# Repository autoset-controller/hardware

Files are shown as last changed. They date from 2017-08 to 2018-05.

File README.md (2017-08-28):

# Autoset Controller
> Theatrical Controller for Thesis Project

Program for wireless control of motorized platforms in a stage space.

## Developing

### Built With
List main libraries, frameworks used including versions (React, Angular etc...)

### Prerequisites
What is needed to set up the dev environment. For instance, global dependencies or any other tools. include download links.

## Versioning

We can maybe use [SemVer](http://semver.org/) for versioning. For the versions available, see the [link to tags on this repository](/tags).

## Configuration

Here you should write what are all of the configurations a user can enter when
using the project.

## Style guide

Our git style will be implemented from [Wearhive's project guidelines](https://github.com/wearehive/project-guidelines#git).

## Api Reference

If the api is external, link to api documentation. If not describe your api including authentication methods as well as explaining all the endpoints with their required parameters.

## Licensing

State what the license is and how to find the text version of the license.

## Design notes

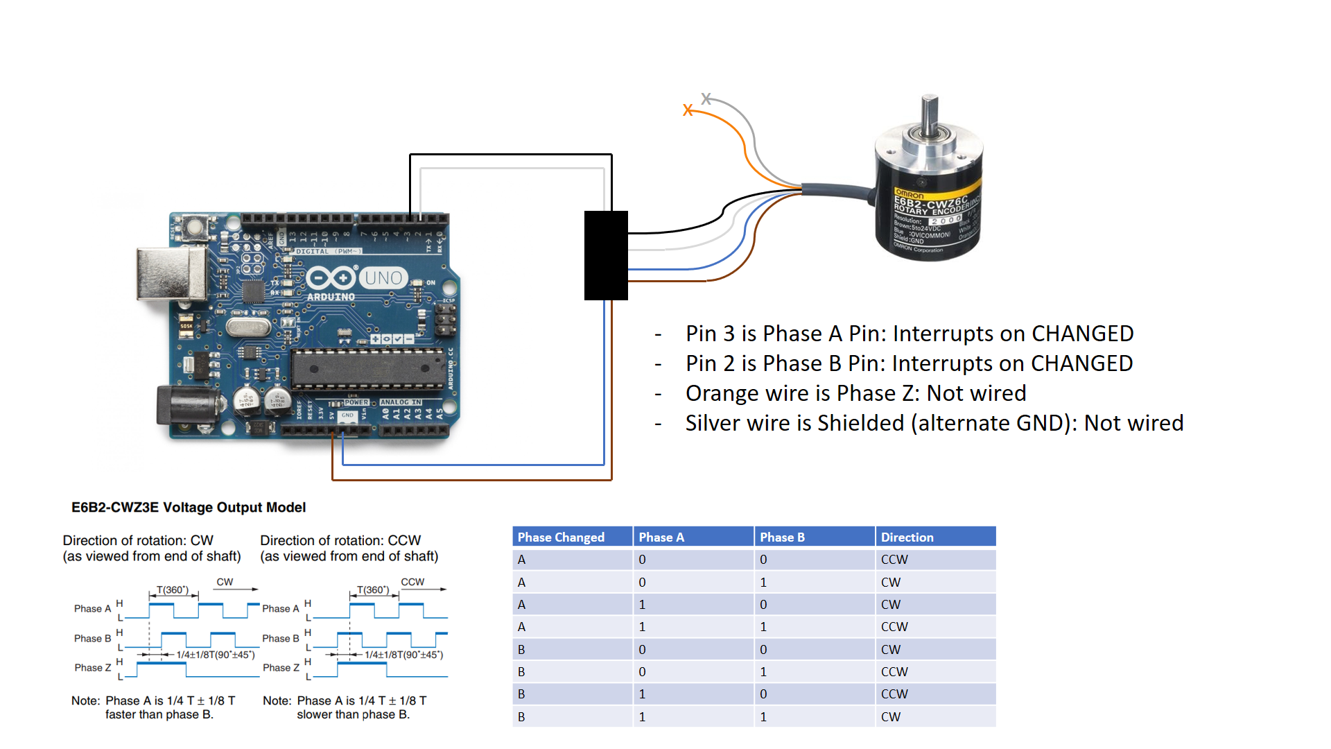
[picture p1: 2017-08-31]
Hardware Interface/Circuit Diagrams/Rotary Encoder E6C2-CW3ZE.png

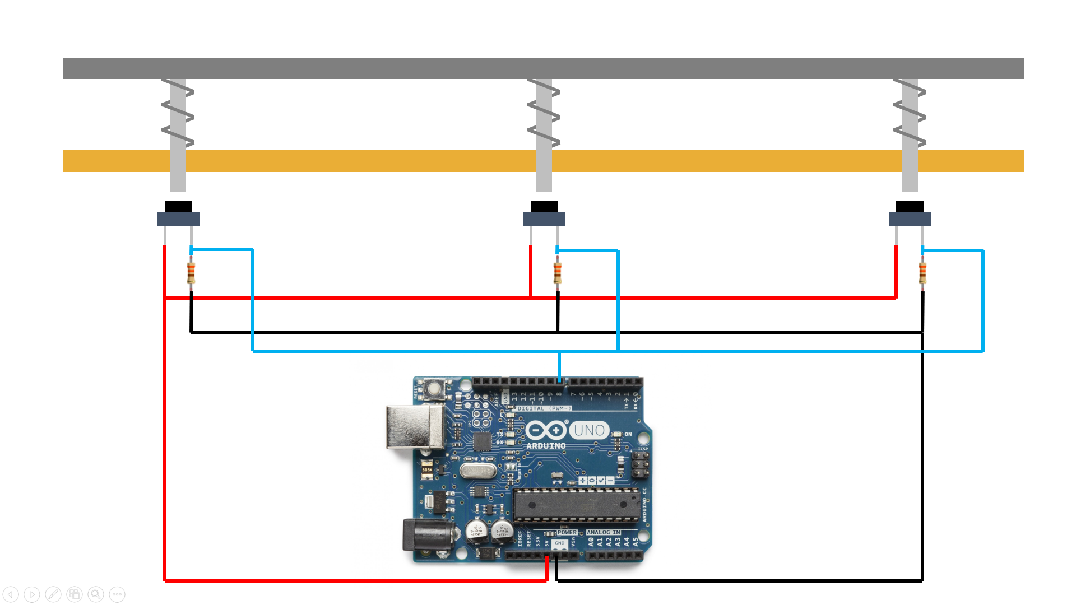
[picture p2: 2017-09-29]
Hardware Interface/Circuit Diagrams/Bumper HOUSE.png

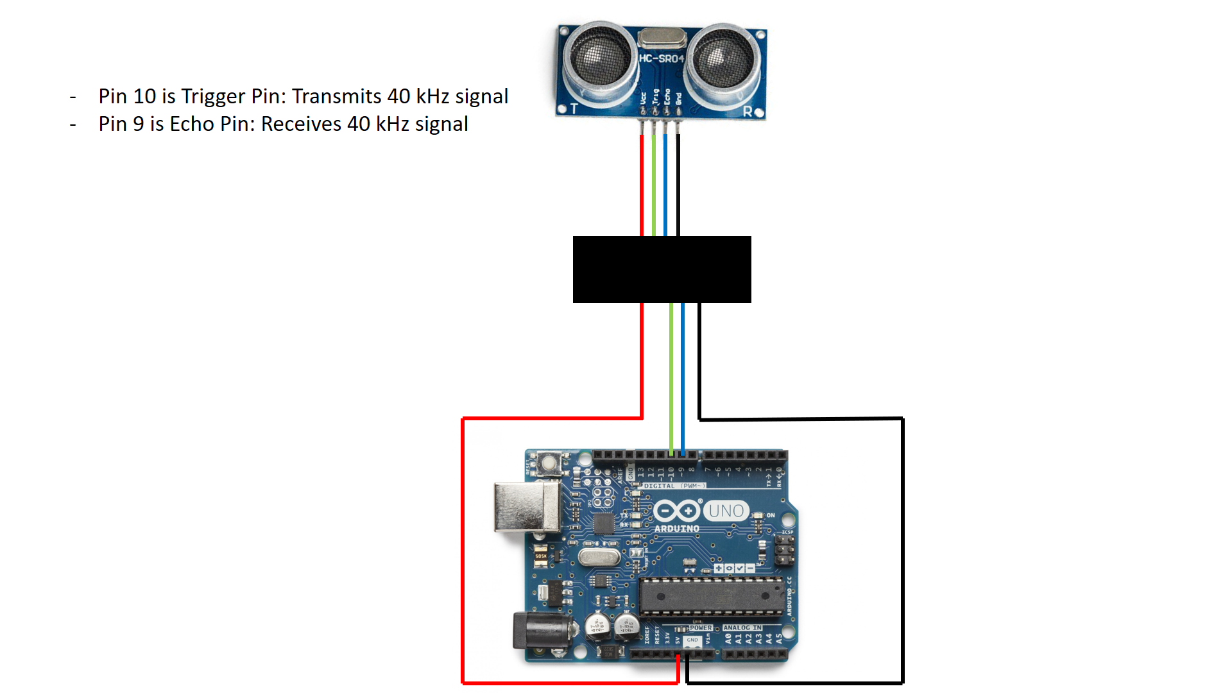
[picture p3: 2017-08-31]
Hardware Interface/Circuit Diagrams/Ultrasonic Sensor HC-SR04.png

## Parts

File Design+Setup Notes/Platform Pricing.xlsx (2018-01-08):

Items | Details | Price | Qty | Total Price | Online/Local | Notes | Source
COTS Hardware Costs:
Drive Wheel | 6" diameter x 3/4" Width | $27 | 4 | $108.00 | Online | 1-week shipping | https://www.amazon.com/6-inch-Drive-Wheels-4-inch-Keyed/dp/B00AGZ6I8M
Ball Bearing | 3/4" SD, 1-3/4" OD | $15.33 | 4 | $61.32 | Online | 1-day shipping | https://www.mcmaster.com/#6384k369/=19hgatr
Roller Chain Sprocket | 11 Teeth, 3/4" SD | $11.78 | 4 | $47.12 | Online | 1-day shipping | https://www.mcmaster.com/#6280k334/=19hgfr6
Roller Chain | 2' long, 3/8" Pitch | $7.80 | 2 | $15.60 | Online | 1-day shipping | https://www.mcmaster.com/#6261k172/=19k67bu
Keyed Rotary Shaft | 12" long, 3/4" diameter | $21.20 | 2 | $42.40 | Online | 1-day shipping | https://www.mcmaster.com/#1497k116/=19khoco
Machine Key Stock | 12" long, 3/16" x 3/16" | $1.16 | 1 | $1.16 | Online | 1-day shipping | https://www.mcmaster.com/#98491a117/=19khr2p
E30-400G Motor/Reducer | Specs available at link. | $289.00 | 2 | $578.00 | Online | 1-week shipping (UPS) | http://www.ampflow.com/ampflow_gearmotors.htm
4" Caster Wheels | 250lb load capacity | $13.92 | 4 | $55.68 | Online | Didn't use this supplier, shop around. | https://www.zoro.com/value-brand-swivel-plate-caster-rubber-4-in-250-lb-1uhy4/i/G0929564
Hardware Total: |  |  |  | $909.28
Electronics Costs:
Rotary Encoder | E6C2-CWZ3E, 1024P/R | $39.95 | 2 | $79.90 | Online | 1-2 week shipping | https://www.sparkfun.com/products/11102
Arduino Uno | Any Compatible Board | $7.59 | 1 | $7.59 | Online | 1-week shipping | https://www.newegg.com/Product/Product.aspx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
Xbee Transmitter | Wire Antenna, 802.15.4 | $19.29 | 3 | $57.87 | Online | 1-week shipping | https://www.digikey.com/product-detail/en/XB24-AWI-001/XB24-AWI-001/935965
Xbee Explorer Board | For USB connectivity | $24.95 | 3 | $74.85 | Online | Shop around, better prices likely. | https://www.sparkfun.com/products/11812
Motor Controller | SyRen 50A 6V-30V Regen | $119.99 | 2 | $239.98 | Online | 1-week shipping | http://www.robotshop.com/en/syren-motor-driver.html
Rechargeable Batteries | 12V 9A Sealed LA (Duracell) | $40.97 | 4 | $163.88 | Local | Price may vary. | https://www.batteriesplus.com/productdetails/sla12=9f2
Recharger | LA Smart Charger (Duracell) | $64.99 | 2 | $129.98 | Local | Price may vary. | https://www.batteriesplus.com/charger/specialty-lead-acid-battery/duracell-ultra/slc10004
Mini USB cables | USB 2 A-Male to Mini-B | $4.79 | 3 | $14.37 | Online | Recommend at least 3 feet. | https://www.amazon.com/AmazonBasics-USB-2-0-Cable-Male/dp/B00NH13S44
47 uF Capacitors | 50V Radial | $0.15 | 10 | $1.50 | Online | You only need 2, but 10 is cheaper. | https://www.jameco.com/z/R47-50-47uF-50V-Radial-Electrolytic-Capacitor-plusmn-20-37-_31114.html
.1 uF Capacitors | Ceramic Disc | $0.12 | 10 | $1.20 | Online | You only need 2, but 10 is cheaper. | https://www.jameco.com/z/DC-01-Ceramic-Disc-Capacitor-0-01-micro-F-50V-plusmn-20-37-Z5U_15229.html
Prototyping Circuit Boards | Any PCB is acceptable. | $4.95 | 2 | $9.90 | Online | Don't use breadboards - use soldering. | https://www.jameco.com/z/SB400-Busboard-Prototype-Systems-SB400-Solderable-PC-Breadboard-1-Sided-PCB-Matches-400-Tie-Point-Breadboards-With-Power-Rails_212505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
24V-5V Converter | To power Raspberry Pi | $7.98 | 2 | $15.96 | Online | Shop around, better prices likely. | https://www.amazon.com/Magnolian-Converter-Regulator-Supplies-Transformer/dp/B00BWLP88A
40 22-Gauge Jumper Wires | For connecting to RPi pins | $6.41 | 1 | $6.41 | Online |  | https://www.amazon.com/dp/B00W8YDCGA/ref=asc_df_B00W8YDCGA5328701
Electronics Total: |  |  |  | $803.39
Total Cost: |  |  |  | $1712.67 | (+ shipping)
Total Cost incl. Materials: |  |  |  | $1977.67
Generic Materials:
1"x1" steel, 4' | Corners cut at 45 deg |  | 8
1"x1" steel, 3'10" |  |  | 4
1"x1" steel, 10" |  |  | 8 |  |  | All metals were purchased locally.
1"x1" steel, 5" |  |  | 4 | ~$90 for 1x1 steel |  | Prices will vary.
1"x4" steel, 10" |  |  | 4 | ~$20 for 1x4 steel |  | Prices will vary.
5" plate steel, 3'10" |  |  | 2 | ~$80 for steel plate |  | Prices will vary.
Plywood, 4'x5" | For platform walls |  | 4
Plywood, 4'x4' | For platform top |  | 1 | ~$20 for plywood
MDF board, 4'x4' | For platform top (above plywood) |  | 1 | ~$20 for MDF board
~1" thick scrap wood | For adjustments on caster wheel heights |  | 4 | Use plywood scraps
Insulated 22-Gauge Wire | For RPi/encoder circuity |  | Excess | ~$20 |  |  | https://www.amazon.com/StrivedayTMFlexible-Silicone-Electric-electronic-electrics/dp/B01LH1FR6M/
Insulated 12-Gauge Wire | For motor/battery circuitry |  | Excess | ~$15 |  |  | https://www.amazon.com/GAUGE-GROUND-PRIMARY-STRANDED-COPPER/dp/B01AO1K5HW/
Total Materials Cost: |  |  |  | $265
Tools Used:
Circular Table Saw | Water Cooled
Arc Welder | Gas Metal (Xenon, Copper)
Table Drill | W/ Oil for spark suppression
Metal Grinder | Incl. Disc Replacements
Circular Portable Saw | Corded
Hammers. | For adjustments.
Tape Measures, Squares, etc. | General measurement/angle tools
Soldering Iron | For circuitry.
Wire Strippers | For stripping wires. | (I actually used the sharp part of the pliers, don't tell Chris)

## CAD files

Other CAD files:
Hardware Design/EncoderMount.dwg

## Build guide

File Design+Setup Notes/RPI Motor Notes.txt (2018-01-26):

Current configuration uses pulse width modulation mode via the SyRen motor controller.

Minimum signal that produces movement is: 80
Minimum signal that produces tangible force is: 256
Maximum signal is: 1024
Field tests will need to be run to determine what the actual minimum is when the motor has weight on it.

There are multiple pins that can handle OS-level pwm signals. 
For the purpose of this project, pins 12 and 32 (1 and 26, in wiringPi) will be used.
(Alternatively, a serial packet-based control system could be used, as the motor controllers can handle that.
This decision will depend on how well the TXD (wire-based) serial connection can be established.

Pin Setup:

Motor Controller 5V: 5V (Pin 4)
Motor Controller 0V: 0V (Pin 6)
Motor Controller S1: 1/26 (Pins 12/32)
Motor Controller S2: 0/2 (Pins 11/13)

Pins must go through the circuit outlined at the following link, page 13, fig 4.2:
https://www.dimensionengineering.com/datasheets/SyRen50.pdf
This will smooth out PWM and make it act as an analog output.

TODO: 
- Introduce emergency stop mechaninism (e.g. switch activated by button on side of platform.
  This stop mechanism must stop both motors until power is cycled (or until reset switch is activated).

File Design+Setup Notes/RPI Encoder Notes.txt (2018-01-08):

With the current setup (i.e. each interrupt merely increments position, and calculations are run in main):
Maximum platform speed is approximately 0.78 ft/s, or .24 m/s, assuming encoder wheel radius of 6".
Moving any faster would result in dropped/misinterpreted interruptions.

To improve the permissible speed of the platform while maintaining position consistency, there are two options:
- Reduce the rotation rate of the encoder - e.g. increase wheel size, or gear down the encoder.
- Reduce the fidelity of the encoder - e.g. use a 256 P/R encoder, rather than a 1024 P/R encoder.

The second option has the added benefit of reducing the cost of the platform.
However, both options sacrifice accuracy in the sense that fewer ticks will be counted.
They will cause the platform path to become less certain in a shorter time, because they will multiply error.

To determine the optimal ratio of fidelity to speed, practical tests must be run.
To that end, I will focus on making the communication program (between platform and desktop) functional.
After that, fidelity tracking will begin.

Acceptable error per cycle: .1 cm
Encoder position error = 2*pi*r / TICKS_PER_CYCLE
Assuming 6" radius, 4096 ticks per cycle: error = .023 cm, well within acceptable bounds.
Assuming 6" radius, 1024 ticks per cycle: error = .094 cm, just within acceptable bounds.

The 1024 ticks per cycle error is recommended, as it will permit speeds of approximately 1 m/s.
As increasing the wheel size is not a viable option (the platform is only 8"), the following options are recommended:
- Gear encoder for torque by 4:1
	-or-
- Swap to 256 P/R encoder

Pin Locations:

Encoder Blue: 5V (GPIO 4)
Encoder Brown: 0V (GPIO 6)
Encoder Black (Phase A): 0/2 (GPIO 11/13)
Encoder White (Phase B): 1/3 (GPIO 12/15)

Console Setup:

$ gpio mode 0 in
$ gpio mode 1 in

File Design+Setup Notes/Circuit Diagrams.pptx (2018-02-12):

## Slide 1

x

x

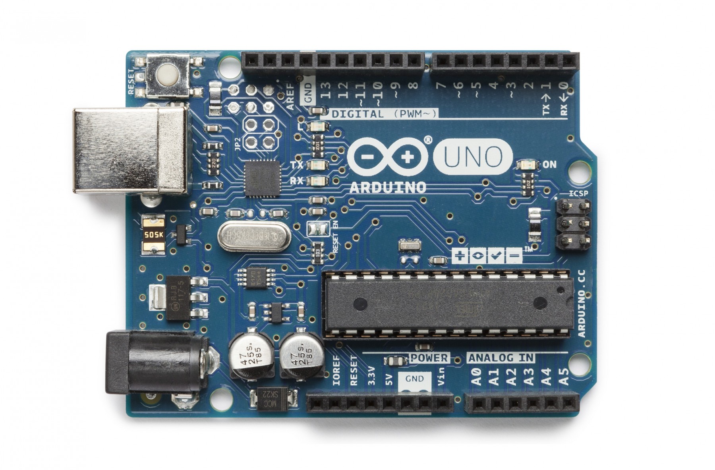
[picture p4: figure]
Image result for arduino uno

- Pin 3 is Phase A Pin: Interrupts on CHANGED
- Pin 2 is Phase B Pin: Interrupts on CHANGED
- Orange wire is Phase Z: Not wired
- Silver wire is Shielded (alternate GND): Not wired

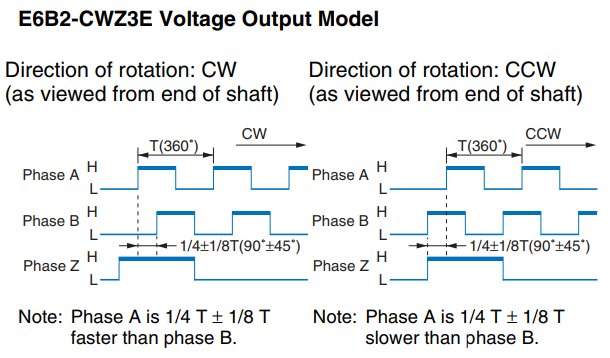
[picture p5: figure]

Phase Changed | Phase A | Phase B | Direction
A | 0 | 0 | CCW
A | 0 | 1 | CW
A | 1 | 0 | CW
A | 1 | 1 | CCW
B | 0 | 0 | CW
B | 0 | 1 | CCW
B | 1 | 0 | CCW
B | 1 | 1 | CW

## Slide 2

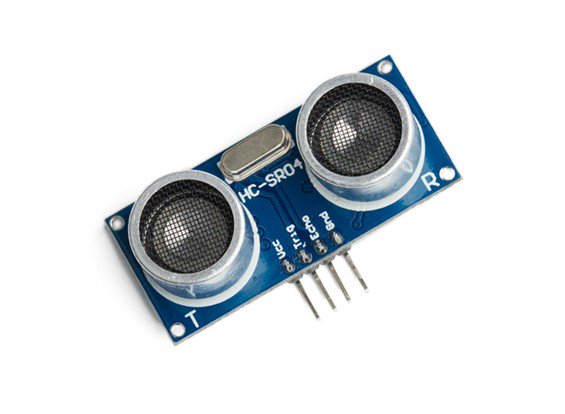
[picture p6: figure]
Ultrasonic Distance Sensor Module HC-SR04 for Kingduino

- Pin 10 is Trigger Pin: Transmits 40 kHz signal
- Pin 9 is Echo Pin: Receives 40 kHz signal

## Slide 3

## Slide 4

x

x

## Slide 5


GPIO 14/RXD0: Serial Receive

GPIO 15/TXD0: Serial Transmit

GPIO 20: Encoder 2 Phase A

GPIO 6: Encoder 1 Phase B

GPIO 5: Encoder 1 Phase A

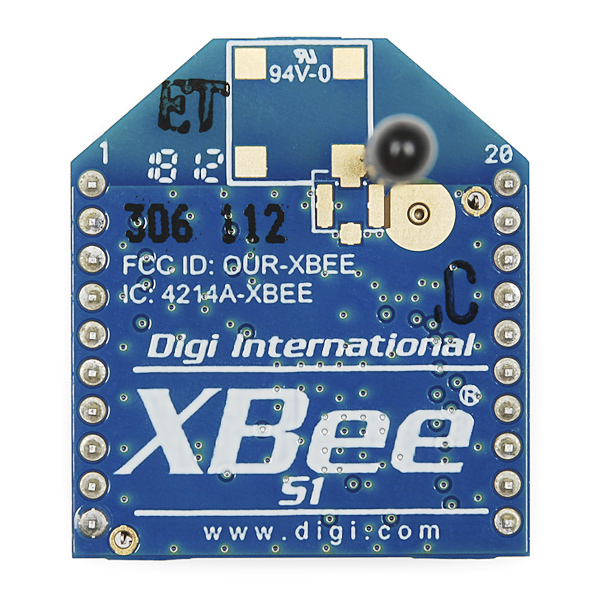
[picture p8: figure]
Image result for xbee

Xbee Radio:
Send Address: 3333
My Address: 44<Platform Number> (e.g. 4401, 4402)
Baud: 38400

GPIO 21: Encoder 2 Phase B

GPIO 16: Emergency Stop
(LOW == Stop)

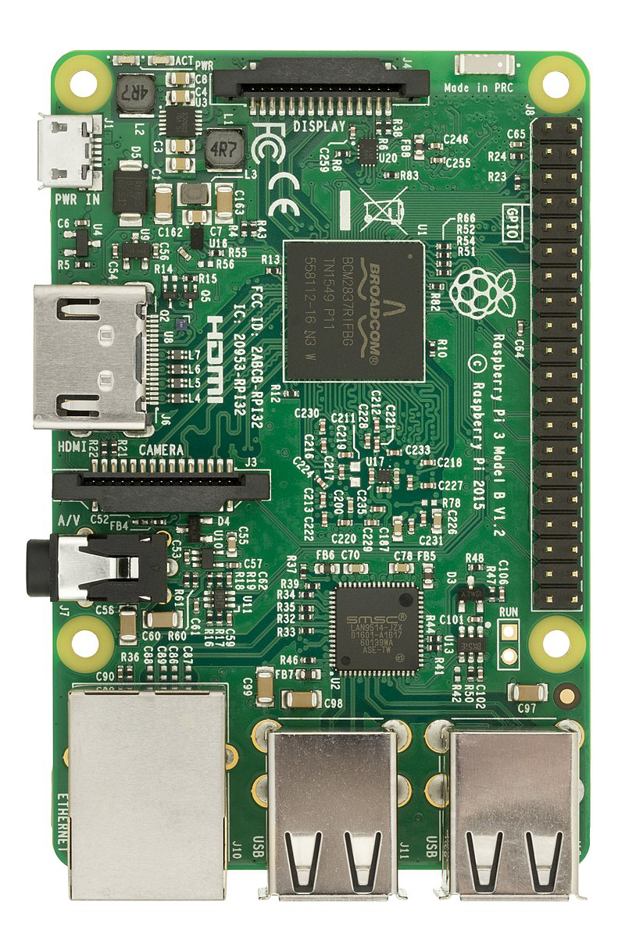
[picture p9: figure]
Image result for raspberry pi
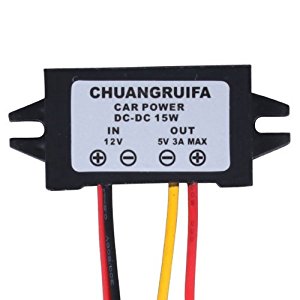
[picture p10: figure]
Image result for 12v to 5v converter

Controller 1:
Packetized Serial, address 128
Baud: 38400

Controller 2:
Packetized Serial, address 135
Baud: 38400

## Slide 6

0V/GND

PWM

DOUT

INTERRUPT A

INTERRUPT B

5V

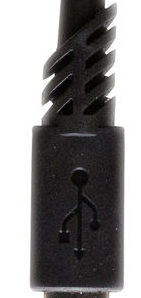
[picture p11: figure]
Image result for microusb
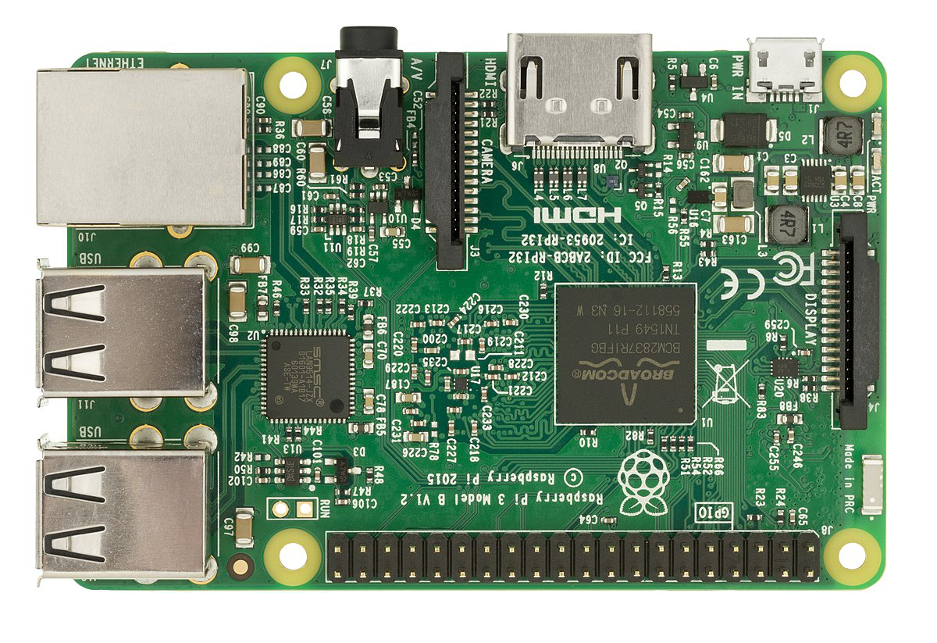
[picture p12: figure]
Image result for raspberry pi
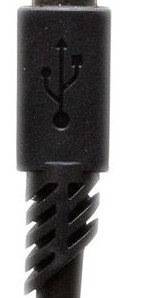
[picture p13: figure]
Image result for microusb
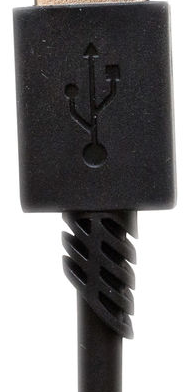
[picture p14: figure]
Image result for microusb

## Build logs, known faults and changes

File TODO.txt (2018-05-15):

Things to do:

Logistics:
- Patent AutoSet Controller and AutoSet FreeRoam
- Trademark the AutoSet brand

Hardware:
- Fix the encoder wheel mount
- Fix charging cables
- Build a miniature prototype to demonstrate multi-platform capabilities of the software.
- Test microphone-based communication/research linear time code
- Perform reliability/distance testing for XBee
- Perform speed/weight/power testing for platform motors, generate curveset
- Perform speed/reliability testing for platform encoders
- Make tutorial for construction of platform

Drivers:
- Refactor drivers so that methods intake required inputs.
- Remove looping inside packet processing, or reduce its impact.
- Implement configuration broadcast, configuration response processing.
- Implement response for E_STOP and PAUSE.
- Make tutorial for loading drivers onto platform.

Controller:
- Implement handshakes on E_STOP, PAUSE, attribute setting, and motor commands.
- Each platform should have a window size of 1 for packet send/receive.
- Implement configuration for COM ports, xbox controller.
- Implement configuration for platforms (platform ID, platform color, attributes, etc.).
- Implement adding, modifying, and deleting cues.
- Implement cue grouping, auto-follow, and auto-continue.
- Implement drawing cues, populating waypoints.
- Implement autogeneration of waypoints when driving.
- Connect with local storage to allow saving of attributes.
- Research importing descriptor files to render stage limits.
- Ensure that platforms never go past stage limits, both when generating cues and when driving.
- Implement adding objects of varying shape and size.

Website:
- Make the website.
- Host executables, drivers, and link to github.

Backburner:
- Implement encryption?
- Implement free roaming camera.

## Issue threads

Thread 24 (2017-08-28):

Add Error Processing

parion, 2017-08-28:
Add functionality to process errors from ultrasonic and touch sensors on platform. _Behavior should be similar to stop command._

Closed 2023-05-19.

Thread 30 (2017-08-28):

Projection Mapping Bug Megathread

parion, 2017-08-28:
Megathread for all bugs for projection mapping milestone. Reference all corresponding issues to this thread.

Closed 2023-05-19.

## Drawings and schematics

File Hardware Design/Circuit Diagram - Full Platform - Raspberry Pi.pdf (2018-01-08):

### Xbee Radio: Send Address: 3333

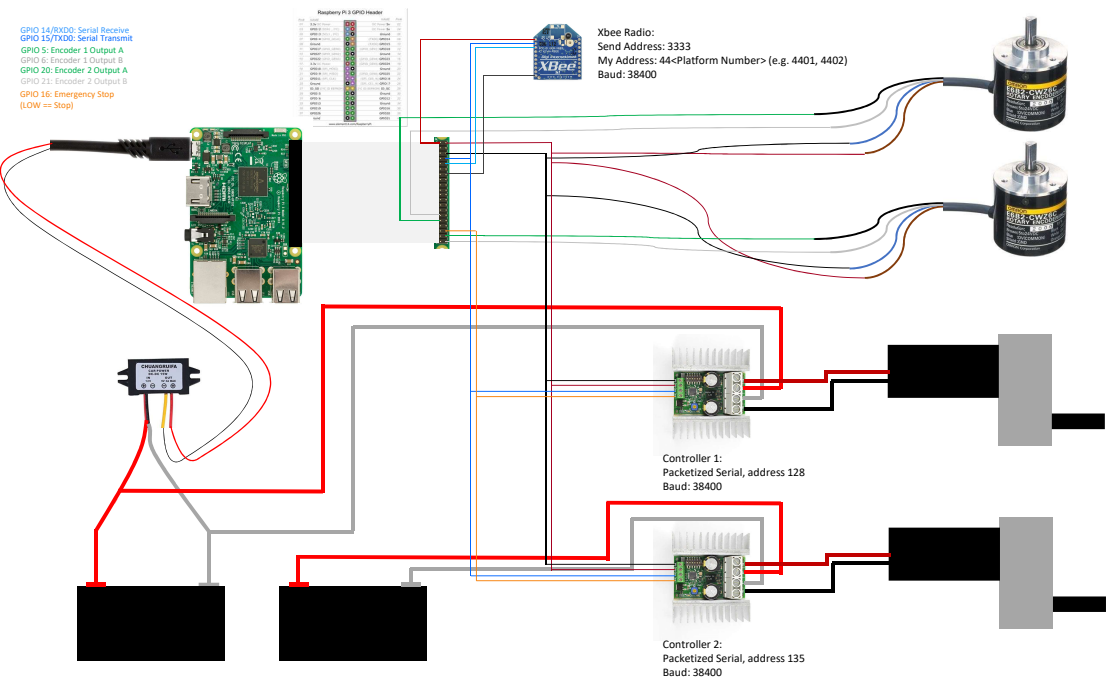
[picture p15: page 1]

GPIO 14/RXD0: Serial Receive
GPIO 15/TXD0: Serial Transmit
GPIO 5: Encoder 1 Output A
GPIO 6: Encoder 1 Output B
Baud: 38400 GPIO 20: Encoder 2 Output A
GPIO 21: Encoder 2 Output B
GPIO 16: Emergency Stop
(LOW == Stop)

My Address: 44<Platform Number> (e.g. 4401, 4402)

Controller 1:
Packetized Serial, address 128
Baud: 38400

Controller 2:
Packetized Serial, address 135

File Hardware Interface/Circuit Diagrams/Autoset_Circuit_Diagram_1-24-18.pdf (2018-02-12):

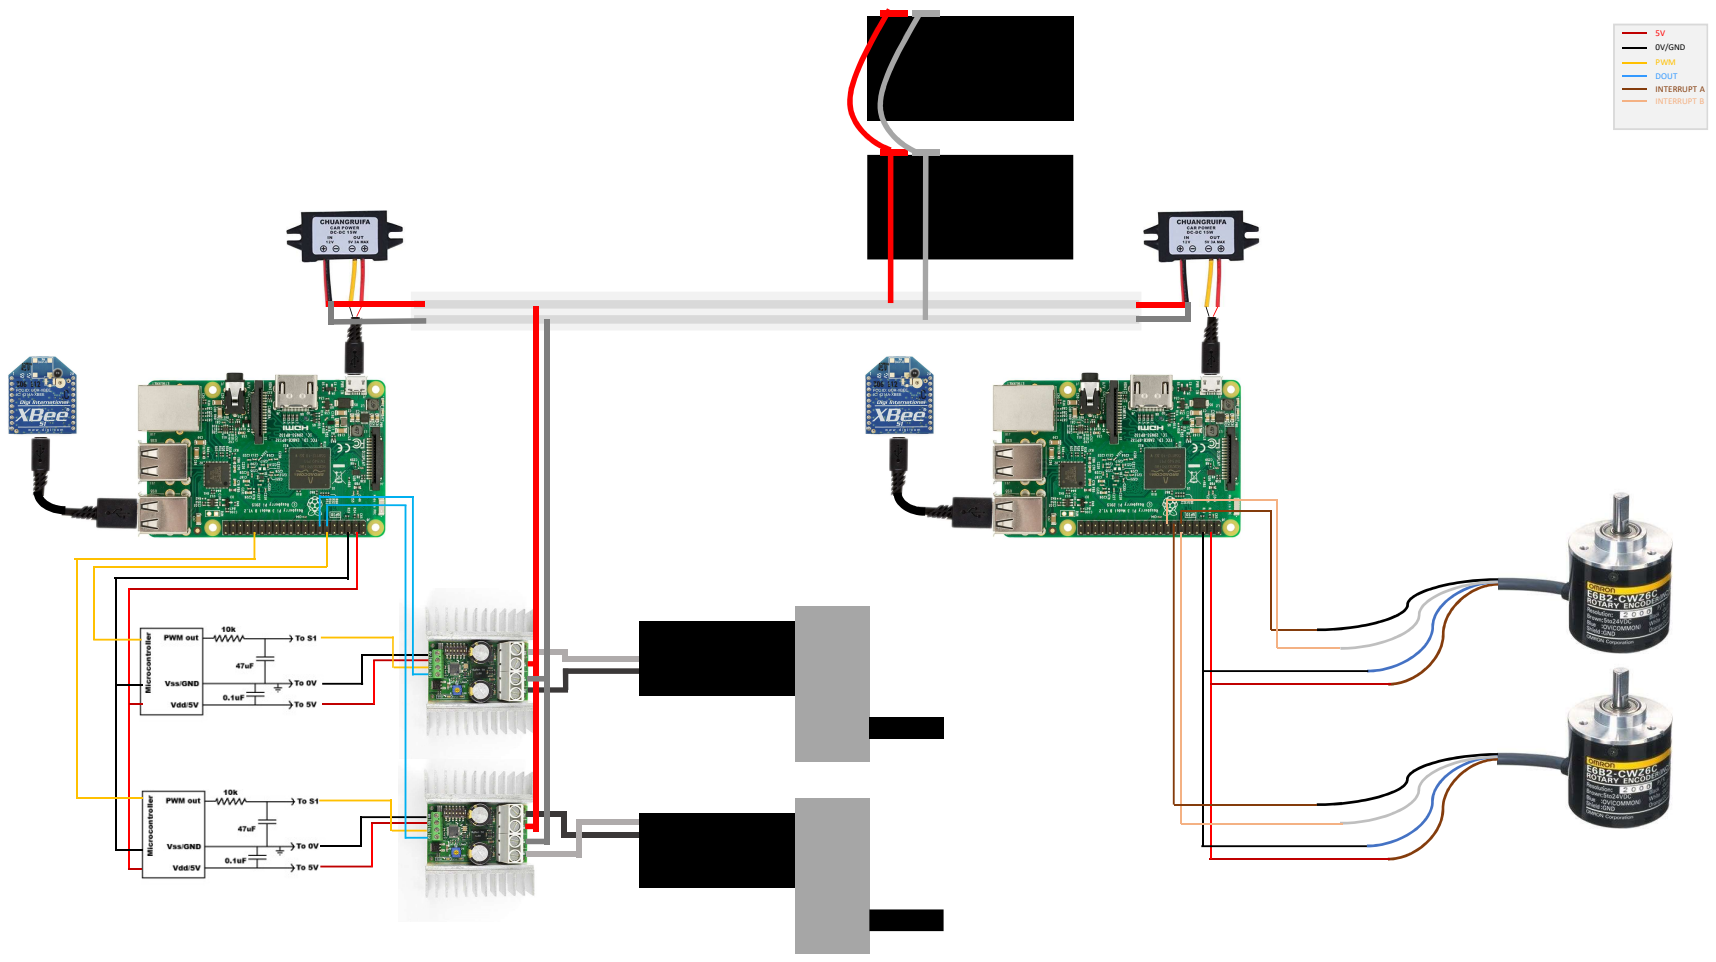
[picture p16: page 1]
5V 0V/GND PWM DOUT INTERRUPT A INTERRUPT B

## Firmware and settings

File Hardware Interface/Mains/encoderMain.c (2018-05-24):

#include <math.h>
#include <string.h>
#include <stdio.h>
#include <stdlib.h>
#include <wiringPi.h>
#include <wiringSerial.h>

#define debug 1
#define DEBUG(args ...) if(debug) { printf(args); }

//pin values
#define phaseAPinL 0
#define phaseBPinL 1
#define phaseAPinR 2
#define phaseBPinR 3

//system info
#define XBEE_BAUD 57600
#define UPDATE_SIZE_MAX 128
#define UPDATE_SIZE_MIN 64
#define ALL_TYPES 999

//CONSTANTS
int update_size = 64; //minimum # updates to trigger a packet send
int update_match = 0;
double radius = .2625 * .3048; //radius of encoder wheels (m)
double encoderDist = 1.484375 * .3048; //distance between encoder wheels (m)
double motorDist = 2.5416666 * .3048; //distance between motor wheels
double TICKS_PER_CYCLE = 4096; //P/R on encoder * 4

//forward decl
int getInitResponse();
void clearInitPacket();
void getSerialData();
int processPacket(int, double, double, double, double);
void sendPositionPacket(double, double, double);
void clearLine(int);
void clearPacket();

void phaseA_R();
void phaseB_R();
void phaseA_L();
void phaseB_L();

//interrupt info
double dR;
double dL;

int A_L, B_L, A_R, B_R;

//pos info
double x, y, theta; //current position (m, m, rad)
double dx, dy, dtheta; //change in position (m, m, rad)
double checksum;

char x_str[128];
char y_str[128];
char theta_str[128];
char checksum_str[128];

//setup info
int serialXBee;
int serialGPIO; //for communication from the encoder brain to the motor brain
int update;

//Computer Info
char delim = '|';
int key = -1;
int platform = -1;
int type = 1; //0 for motor brain, 1 for encoder brain
char mac_address[256]; //MAC address (eth0) of brain
char platform_name[256] = "freeroam";

//serial packet info
int valuesLoaded = 0;
int initialized = 0;
int initPacketDetected = 0;

//init
char init_str[128];
char response_init_str[128];
char mac_init_str[128];
char key_init_str[128];
char platform_init_str[128];
char encoderdist_init_str[128];
char encoderradius_init_str[128];
char encoderticks_init_str[128];
char checksum_init_str[128];

int response_init;
int key_init;
int platform_init;
double encoderdist_init;
double encoderradius_init;
int encoderticks_init;
double checksum_init;

//general operation
char key_in_str[128];
char plat_in_str[128];
char type_in_str[128];
char id_in_str[128];
char comm_in_str[128];
char val1_in_str[128];
char val2_in_str[128];
char val3_in_str[128];
char checksum_in_str[128]; //checksum = comm + val1 + val2 + val3

int key_in;
int plat_in;
int type_in;
int id_in;
int comm_in;
double val1_in;
double val2_in;
double val3_in;
double checksum_in;

//Test program that send the position of a platform driving in circles.
int main(int argc, char* argv)  {

	DEBUG("Booting Encoder Brain...\n");
	delay(2000);
	DEBUG("MAC address: ");
	FILE* mac = fopen("/sys/class/net/eth0/address", "r");
	//DEBUG("mac open\n");
	fgets(mac_address, 255, mac);
	//DEBUG("got mac_address\n");
	fclose(mac);
	mac_address[17] = '\0';
	DEBUG("%s\n", mac_address);

	wiringPiSetup();
	serialXBee = serialOpen("/dev/ttyUSB0", XBEE_BAUD);
	serialGPIO = serialOpen("/dev/ttyS0", XBEE_BAUD);

	//Broadcast MAC address and platform name, and wait for response from controller
	char initString[256];
	sprintf(initString, "init|%s|%s|%s|%s|\n", mac_address, mac_address, mac_address, platform_name);

	DEBUG("Waiting for configuration...\n");

	while(initialized != 1) {
		printf("sending out packet: %s", initString);
		serialPuts(serialXBee, initString);
		//delay
		int i = 0, j = 0;
		for(i = 0; i < 32767; i++) {
			for(j = 0; j < 32767; j++) {}
		}

		if(serialDataAvail(serialXBee) > 0) {
			getInitResponse(serialXBee);
		}
	}

	DEBUG("Configuration Response Received.\n");

	//send init values to motor brain
	char keyString[256];
	char platString[256];
	sprintf(keyString, "-1|-1|0|0|1|0|%d|%d|%d|\n", key, key, key+key);
	sprintf(platString, "%d|-1|0|0|1|1|%d|%d|%d|\n", key, platform, platform, platform+platform);
	serialPuts(serialGPIO, keyString);
	serialPuts(serialGPIO, platString);

	DEBUG("Sent configuration to motor brain.\n");

	//send handshake to controller
	char handshake[256];
	sprintf(handshake, "init|%s|%d|\n", mac_address, key);
	serialPuts(serialXBee, handshake);

	DEBUG("Sent handshake to controller.\n");

	//Initialize encoder pins
	pinMode(phaseAPinL, INPUT);
	pinMode(phaseBPinL, INPUT);
	pinMode(phaseAPinR, INPUT);
	pinMode(phaseBPinR, INPUT);

	//Initialize function for encoder interrupts
	int phaseAFuncR = wiringPiISR(phaseAPinR, INT_EDGE_BOTH, phaseA_R);
	int phaseBFuncR = wiringPiISR(phaseBPinR, INT_EDGE_BOTH, phaseB_R);
	int phaseAFuncL = wiringPiISR(phaseAPinL, INT_EDGE_BOTH, phaseA_L);
	int phaseBFuncL = wiringPiISR(phaseBPinL, INT_EDGE_BOTH, phaseB_L);

	x = 0; y = 0; theta = 0;
	dx = 0; dy = 0; dtheta = 0;

	double dR_in, dL_in;
	int updates_in;

	int wait = 0;

	while(1) {
		//Check for serial data
		if(serialDataAvail(serialXBee) > 0) {
			//interpret serial data and act on it
			getSerialData(serialXBee);
		}

		//calculate change in x,y,theta
		if(update >= update_size) {
			//DEBUG("updates: %d\n", update);
			//Process update and clear transfer values
			dR_in = dR;
			dL_in = dL;
			updates_in = update;

			dR = 0;
			dL = 0;
			update = 0;

			//interrupts can now safely modify these values
			DEBUG("%d: %f, %f\n", updates_in, dL_in, dR_in);

			//update update size to process updates efficiently
			if(updates_in <= update_size) { // if updates were processed without delay
				update_match++;
				//if updates are consistently processed without delay, attempt to lower the update size
				if(update_match >= update_size) {
					update_match = 0;
					if(update_size > UPDATE_SIZE_MIN * 2) {
						update_size /= 2;
					}
					else if(update_size > UPDATE_SIZE_MIN) {
						update_size -= 1;
					}
				}
			}
			else { //if updates were processed with some delay
				if(update_size < UPDATE_SIZE_MAX / 2) {
					update_size *= 2;
				}
				else if(update_size < UPDATE_SIZE_MAX) {
					update_size += 1;
				}
			}

			dR_in = dR_in * 2 * M_PI / TICKS_PER_CYCLE;
			dL_in = dL_in * 2 * M_PI / TICKS_PER_CYCLE;

			dtheta = radius / encoderDist * (dR_in - dL_in);
			theta = theta + dtheta;
			theta = fmod(theta, 2 * M_PI);

			// |x| = |x0| + |cos(theta) cos(theta)| * |dR| = |x0| + r/2 * |cos(theta)*dR + cos(theta) * dL|
			// |y|   |y0|   |sin(theta) sin(theta)|   |dL|   |y0| +       |sin(theta)*dR + sin(theta) * dL|

			// x = x0 + r/2 * cos(theta) * (dR + dL)
			// y = y0 + r/2 * sin(theta) * (dR + dL)

			x = x + radius / 2 * cos(theta) * (dR_in + dL_in);
			y = y + radius / 2 * sin(theta) * (dR_in + dL_in);

			sendPositionPacket(x, y, theta);
		}
	}

	return 0;
}

///PACKET FUNCTIONS:

// process init response from controller
// response should look like:
// "init|<response id>|<MAC_ADDRESS>|<key>|<platform id>|<radius>|<encoder distance>|<ticks per rotation>|<checksum>|\n"
int getInitResponse(int port) {
	while(serialDataAvail(port)) {
		char c = (char)serialGetchar(port);
		DEBUG("%c", c);
		//add loaded value
		if(c == '|') {
			valuesLoaded += 1;
			//preemptively ignore packets
			switch(valuesLoaded) {
				case 1:
					if(strcmp(init_str, "init") != 0) {
						DEBUG("ignoring packet: not an init packet\n");
						clearLine(port);
						clearInitPacket();
					}
					break;
				case 3:
					//if MAC addresses do not match, ignore the packet
					if(strcmp(mac_init_str, mac_address) != 0) {
						DEBUG("ignoring packet: mac address mismatch\n");
						clearLine(port);
						clearInitPacket();
						return 0;
					}
					break;
			}
		}
		//process completed packet
		else if(c == '\n') {
			//if the wrong number of packet values have been loaded, ignore the packet
			if(valuesLoaded != 9) {
				clearInitPacket();
				return 0;
			}
			//load values
			response_init = atoi(response_init_str);
			key_init = atoi(key_init_str);
			platform_init = atoi(platform_init_str);
			encoderdist_init = atof(encoderdist_init_str);
			encoderradius_init = atof(encoderradius_init_str);
			encoderticks_init = atoi(encoderticks_init_str);
			checksum_init = atof(checksum_init_str);

			//confirm checksum matches radius + distance + ticks (within tolerance)
			double check = encoderdist_init + encoderradius_init + (double)encoderticks_init;
			if(check < checksum_init - 0.000002 || check > checksum_init + 0.000002) {
				clearInitPacket();
				return 0;
			}

			//attempt to load values into memory
			int isBad = 0;
			isBad += processPacket(1, 0, key_init, key_init, 0 + key_init + key_init);
			isBad += processPacket(1, 1, platform_init, platform_init, 1.0 + platform_init + platform_init);
			isBad += processPacket(1, 2, encoderdist_init, encoderdist_init, 2.0 + encoderdist_init + encoderdist_init);
			isBad += processPacket(1, 3, encoderradius_init, encoderradius_init, 3.0 + encoderradius_init + encoderradius_init);
			isBad += processPacket(1, 4, encoderticks_init, encoderticks_init, 4.0 + encoderticks_init + encoderticks_init);

			//if any values are invalid, reject the packet and return bad string
			char iString[128];
				if(isBad > 0) {
				sprintf(iString, "bad:%d\n", response_init);
				clearInitPacket();
				return 0;
			}
			//if all values are valid, return good string and terminate initialization
			else {
				sprintf(iString, "good:%d\n", response_init);
				clearInitPacket();
				initialized = 1;
				return 1;
			}
		}
		//read input char
		else {
			char tmp[2] = "\0\0";
			tmp[0] = c;

			// "init|<response id>|<MAC_ADDRESS>|<key>|<platform id>|<encoder distance>|<radius>|<ticks per rotation>|<checksum>|\n"
			switch(valuesLoaded) {
				//process init entry
				case 0:
					strcat(init_str, tmp);
					break;

				//process response id entry
				case 1:
					strcat(response_init_str, tmp);
					break;

				//process MAC entry
				case 2:
					strcat(mac_init_str, tmp);
					break;

				//process key entry
				case 3:
					strcat(key_init_str, tmp);
					break;

				//process platform id entry
				case 4:
					strcat(platform_init_str, tmp);
					break;

				//process encoderDist entry
				case 5:
					strcat(encoderdist_init_str, tmp);
					break;

				//process radius entry
				case 6:
					strcat(encoderradius_init_str, tmp);
					break;

				//process ticks entry
				case 7:
					strcat(encoderticks_init_str, tmp);
					break;

				//process checksum entry
				case 8:
					strcat(checksum_init_str, tmp);
					break;

				//all values processed
				default:

					break;
			}
		}
	}
}

//process data from controller
//packet format: key|platform|type|packet_id|comm|val1|val2|val3|checksum|\n
void getSerialData(int port) {
	int valuesLoadedLocal = 0; //to ensure that only one word is processed at a time, mitigating the effects of packet flooding
	while(serialDataAvail(port) > 0 && valuesLoadedLocal == 0) {
		char c = (char)serialGetchar(port);
		DEBUG("%c", c);
		if(c == '|') {
			valuesLoaded += 1;
			valuesLoadedLocal += 1;
			//preemptively ignore packets
			switch(valuesLoaded) {
				case 1:
					if(strcmp(key_in_str, "init") != 0) {
						key_in = atoi(key_in_str);
						if(key_in != key) {
							DEBUG("ignoring packet: key mismatch\n");
							clearLine(port);
							clearPacket();
						}
					}
					else {
						initPacketDetected = 1;
					}
					break;
				case 2:
					plat_in = atoi(plat_in_str);
					DEBUG(plat_in_str);
					if(strcmp(plat_in_str, "PING") == 0) {
						DEBUG("responding to PING...\n");
						sendPositionPacket(x, y, theta);
						clearLine(port);
						clearPacket();
						break;
					}

					if(plat_in != platform && plat_in && initPacketDetected != 1) {
						DEBUG("ignoring packet: platform mismatch\n");
						clearLine(port);
						clearPacket();
					}
					break;
				case 3:
					type_in = atoi(type_in_str);
					if(type_in != type && type_in != ALL_TYPES && initPacketDetected != 1) {
						DEBUG("ignoring packet: type mismatch\n");
						clearLine(port);
						clearPacket();
					}
					else if(initPacketDetected == 1) {
						if(strcmp(type_in_str, mac_address) == 0) {
							DEBUG("extra init packet detected. sending verification.");
							char handshake[256];
							sprintf(handshake, "%s|%d|\n", mac_address, key);
							serialPuts(serialXBee, handshake);
						}
					}
					break;
			}
		}
		else if(c == '\n') {
			//Display packet info
			DEBUG("key_in: %s\n", key_in_str);
			DEBUG("plat_in: %s\n", plat_in_str);
			DEBUG("type_in: %s\n", type_in_str);
			DEBUG("id_in: %s\n", id_in_str);
			DEBUG("comm_in: %s\n", comm_in_str);
			DEBUG("val1_in: %s\n", val1_in_str);
			DEBUG("val2_in: %s\n", val2_in_str);
			DEBUG("val3_in: %s\n", val3_in_str);
			DEBUG("checksum_in: %s\n", checksum_in_str);

			//process all inputs
			int ignore = 0;
			int isBad = 0;
			//If fewer than 4 values have been loaded, we cannot tell if this packet was sent from the controller.
			if(valuesLoaded < 4) {
				//ignore packet
				DEBUG("too few values loaded, ignoring: %d\n", valuesLoaded);
				ignore = 1;
			}
			//Otherwise, we need to check and see if the values are valid.
			else {
				//target_L should be an integer between 0 and 1. Otherwise, packet is bad.
				comm_in = atoi(comm_in_str);
				if(comm_in < 0 || comm_in > 1) {
					isBad = 1;
					DEBUG("comm out of bounds: %d\n", comm_in);
				}
				//val1-val3 should be doubles. Otherwise, packet is bad.
				val1_in = atof(val1_in_str);
				val2_in = atof(val2_in_str);
				val3_in = atof(val3_in_str);
				DEBUG("values: %f, %f, %f\n", val1_in, val2_in, val3_in);
				//checkSum should be equal to the value of target_L_in + target_R_in. Otherwise, packet is bad.
				checksum_in = atof(checksum_in_str);
				isBad = processPacket(comm_in, val1_in, val2_in, val3_in, checksum_in);
			}
			if(!ignore) {
				char badString[8] = "bad:";
				char goodString[8] = "good:";
				char* pString;
				if(isBad) {
					strcat(badString, id_in_str);
					pString = badString;
				}
				else {
					strcat(goodString, id_in_str);
					pString = goodString;
					update = 1;
				}
				//acknowledge packet
				DEBUG("sending packet %s...\n", pString);
				serialPuts(port, pString);
			}
			else {
				DEBUG("ignoring packet\n");
			}
			clearPacket();
		}
		else {
			char tmp[2] = "\0\0";
			tmp[0] = c;

			switch(valuesLoaded) {
				//process key entry
				case 0:
					strcat(key_in_str, tmp); //add next char to key
					break;

				//process platform entry
				case 1:
					strcat(plat_in_str, tmp); //add next char to platform
					break;

				//process target entry
				case 2:
					strcat(type_in_str, tmp); //add next char to type
					break;

				//process platform id
				case 3:
					strcat(id_in_str, tmp); //add next char to id
					break;

				//process comm entry
				case 4:
					strcat(comm_in_str, tmp); //add next char to comm
					break;

				//process val1 entry
				case 5:
					strcat(val1_in_str, tmp); //add next char to val1
					break;

				//process val2 entry
				case 6:
					strcat(val2_in_str, tmp); //add next char to val2
					break;

				//process val3 entry
				case 7:
					strcat(val3_in_str, tmp); //add next char to val3
					break;

				//process checksum entry
				case 8:
					strcat(checksum_in_str, tmp); //add next char to checksum
					break;

				//all values processed
				default:

					break;
			}
		}
	}
}

int processPacket(int comm, double val1, double val2, double val3, double checksum) {
	int isBad = 0;

	//checkSum should be equal to the value of target_L_in + target_R_in. Otherwise, packet is bad.
	if(checksum < val1 + val2 + val3 - 0.000001 || checksum > val1 + val2 + val3 + 0.000001) {
		isBad = 1;
		DEBUG("checkSum does not match: %f != %f + %f + %f\n", checksum, val1, val2, val3);
		return isBad;
	}

	//Interpret Command
	switch(comm) {
		int attribute;
		double value, valueCheck;
		//Set Position
		case 0:
			x = val1;
			y = val2;
			theta = val3;
			DEBUG("new position: x = %f, y = %f, theta = %f\n", x, y, theta);

			sendPositionPacket(x, y, theta);
			break;

		//Set Attribute
		case 1:
			attribute = (int)val1;
			value = val2;
			valueCheck = val3;
			//Interpret Attribute Type
			switch((int)val1) {
				//KEY
				case 0:
					if((int)value == (int)valueCheck && value > 0) {
						key = (int)value;
						DEBUG("new key: %d\n", key);
					}
					else {
						DEBUG("key set failed: %d != %d\n", value, valueCheck);
					}
					break;
				//PLATFORM ID
				case 1:
					if((int)value == (int)valueCheck && (int)value >= 0) {
						platform = (int)value;
						DEBUG("new platform id: %d\n", platform);
					}
					else {
						DEBUG("platform id set failed: %d != %d\n", (int)value, (int)valueCheck);
						isBad = 1;
					}
					break;
				//BASE (Distance b/t encoder wheels)
				case 2:
					if(value == valueCheck && value > 0) {
						encoderDist = value;
						DEBUG("new base: %f\n", encoderDist);
					}
					else {
						DEBUG("base set failed: %f != %f\n", value, valueCheck);
					}
					break;
				//RADIUS (Radius of encoder wheels)
				case 3:
					if(value == valueCheck && value > 0) {
						radius = value;
						DEBUG("new radius: %f\n", radius);
					}
					else {
						DEBUG("radius set failed: %f != %f\n", value, valueCheck);
					}
					break;
				//TICKS_PER_CYCLE (P/R of encoders * 4)
				case 4:
					if((int)value % 128 == 0 && (int)value == (int)valueCheck) {
						TICKS_PER_CYCLE = (int)value;
						DEBUG("new P/R: %d\n", TICKS_PER_CYCLE);
					}
					else {
						DEBUG("invalid P/R resolution: %d\n", (int)value);
					}
					break;
				default:
					break;
			}
			break;
	}
	return isBad;
}

void sendPositionPacket(double x, double y, double theta) {
	checksum = theta + x + y;

	//format position data for serial output
	sprintf(x_str, "%f", x);
	sprintf(y_str, "%f", y);
	sprintf(theta_str, "%f", theta);
	sprintf(checksum_str, "%f", checksum);

	char packet[128];
	sprintf(packet, "%d|%d|%s|%s|%s|%s\n", key, platform, x_str, y_str, theta_str, checksum_str);

	//DEBUG("sending packet: %s", packet);
	serialPuts(serialXBee, packet);
}

//Clears buffer up to next newline
void clearLine(int port) {
	char x = ' ';
	while(serialDataAvail > 0 && x != '\n') {
		x = (char)serialGetchar(port);
	}
}

void clearInitPacket() {
	init_str[0] = '\0';
	response_init_str[0] = '\0';
	mac_init_str[0] = '\0';
	key_init_str[0] = '\0';
	platform_init_str[0] = '\0';
	encoderdist_init_str[0] = '\0';
	encoderradius_init_str[0] = '\0';
	encoderticks_init_str[0] = '\0';

	valuesLoaded = 0;
}

//Resets packet values
void clearPacket() {
	key_in_str[0] = '\0';
	plat_in_str[0] = '\0';
	type_in_str[0] = '\0';
	id_in_str[0] = '\0';
	comm_in_str[0] = '\0';
	val1_in_str[0] = '\0';
	val2_in_str[0] = '\0';
	val3_in_str[0] = '\0';
	checksum_in_str[0] = '\0';

	valuesLoaded = 0;
}

//INTERRUPT FUNCTIONS
void phaseA_R() {
	A_R = digitalRead(phaseAPinR);
	B_R = digitalRead(phaseBPinR);

	/*State options for phase A interrupt:
	00 = CCW
	01 = CW
	10 = CW
	11 = CCW
	*/

	if(A_R+B_R == 1) {
		dR += 1; //Move position clockwise
	}
	else {
		dR -= 1; //Move position counterclockwise
	}
	update++;
	//DEBUG("dR = %f\n", dR);
	//printf("pos = %d\n", pos);
}

void phaseB_R() {
	A_R = digitalRead(phaseAPinR);
	B_R = digitalRead(phaseBPinR);

	/*State options for phase A interrupt:
	00 = CW
	01 = CCW
	10 = CCW
	11 = CW
	*/

	if(A_R+B_R != 1) {
		dR += 1; //Move position clockwise
	}
	else {
		dR -= 1; //Move position counterclockwise
	}
	update++;
	//DEBUG("dR = %f\n", dR);
	//printf("pos = %d\n", pos);
}

void phaseA_L() {
	A_L = digitalRead(phaseAPinL);
	B_L = digitalRead(phaseBPinL);

	/*State options for phase A interrupt:
	00 = CCW
	01 = CW
	10 = CW
	11 = CCW
	*/

	if(A_L+B_L == 1) {
		dL -= 1; //Move position clockwise
	}
	else {
		dL += 1; //Move position counterclockwise
	}
	update++;
	//DEBUG("dL = %f\n", dL);
	//printf("pos = %d\n", pos);
}

void phaseB_L() {
	A_L = digitalRead(phaseAPinL);
	B_L = digitalRead(phaseBPinL);

	/*State options for phase A interrupt:
	00 = CW
	01 = CCW
	10 = CCW
	11 = CW
	*/

	if(A_L+B_L != 1) {
		dL -= 1; //Move position clockwise
	}
	else {
		dL += 1; //Move position counterclockwise
	}
	update++;
	//DEBUG("dL = %f\n", dL);
	//printf("pos = %d\n", pos);
}

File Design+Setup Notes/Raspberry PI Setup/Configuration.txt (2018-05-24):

Repeat steps 1-6 for both computers:

1. Interface Setup:
	Connect your raspberry pi to:
		a 5V power source (via the micro-usb port)
		a monitor (via the HDMI port)
		a keyboard (via one of the USB ports)
	
	If the pi opens up to a graphical desktop (i.e. not command line):
		Connect your raspberry pi to a mouse. (via one of the USB ports)
		Open the terminal.
		Run $sudo su to gain root privileges
		# raspi-config
		3. Boot Options->B1. Desktop or CLI->B2. Command Line Interface + Automatic login
		3. Boot Options->B3. Splash Screen->Disable Splash Screen
		Finish, # reboot.
		Disconnect the mouse.

	If the pi opens up to command line interface with required login:
		Login with the following credentials:
			username: pi
			password: raspberry
			(Or whatever username/password the pi is set up with)
		Run $sudo su to gain root privileges
		# raspi-config
		3. Boot Options->B1. Desktop or CLI->B2. Command Line Interface + Automatic login
		Finish, # reboot.
	
	If typing Shift+3 brings up a pound symbol, rather than #:
		$ sudo su
		# raspi-config
		4. Internationalisation Options->Keyboard Config
		Choose generic 101-key
		You will see a list of UK keyboards. Choose Other.
	 	Choose English (US).
		Select default keyboard settings (i.e. English(US), no modifications).
		Finish, # reboot.

2. Enable UART serial port:
	$ sudo su
	# raspi-config
	7. Advanced Options->A8. Serial->Disable
	(This prevents boot info from being sent from the UART port, which would cause errors with the motor controllers).
	
	# nano /boot/config.txt
	At the end of the file, replace 'enable_uart=0' with 'enable_uart=1'
	# reboot

	UART serial port should now be enabled. 
	Connect GPIO pins 14 and 15 (TxD and RxD) and run # ./serial_test in ~/Autoset to test the connection.

3. Install required libraries:
	In /home/pi, create a new Autoset directory:
	$ mkdir Autoset

	Gain root access again by running $ sudo su.
	wiringPi (original instructions at http://wiringpi.com/download-and-install/ under Plan B):
		On the Raspberry Pi...
			purge the current installation of wiringPi (it's outdated):
			# apt-get purge wiringpi
			# reboot	
		On an internet-connected computer...
			Go to https://git.drogon.net/?p=wiringPi;a=summary, and download the most recent snapshot.
			(As of 2018-01-21, most recent snapshot is 'Fixed GPIO based address for Pi Zero-W').
			Move the downloaded tar.gz file to a flash drive.
		On the Raspberry Pi...
			Connect the flash drive to the RPi.
			Check the id of the flash drive by running the following command:
			# tail -f /var/log/messages
			Look for a message with the format "sda/sda#" (e.g. sda/sda1). sda# is the id of the flash drive.
			Mount the flash drive by running the following commands:
			# cd /media
			# mkdir flash
			# mount -t vfat -o rw /dev/sda# /media/flash
			Move the .tar.gz file to your local Autoset directory:
			(Note that the wiringPi file name may differ.)		
			# cd /media/flash
			# cp wiringPi-96344ff.tar.gz /home/pi/Autoset
			Extract the library and compile it:
			# cd /home/pi/Autoset
			# tar xfz wiringPi-96344ff.tar.gz
			# cd wiringPi-96344ff.tar.gz
			# ./build
		Note: Running ./build may encounter a fatal error, and reboot the system. 
		If this happens, do the following until successful:
			$ sudo su
			# cd Autoset
			# rm -rf wiringPi-96344ff.tar.gz
			# tar xfz wiringPi-96344ff.tar.gz
			# cd wiringPi-96344ff.tar.gz
			# ./build

4. Test libraries:
	Before testing, reboot the system and reestablish root privileges:
	# reboot
	$sudo su

	To confirm that wiringPi is properly installed, run the following command:
	# gpio readall
	You should see a table of pin numbers, pin modes, and pin states. Pay attention to the wPi and Physical values.
	The programs provided use the wPi numbering system.
	If this fails, see the Note on wiringPi in step 3.

5. Install programs:
	The platform runs on a two-brain system - one raspberry pi controls the motors, one reads the encoders.
	
	Computer A will recieve commands and control the motors. 
	Copy and build the program motorMain.c onto computer A.
	# gcc motorMain.c -o motorMain -lwiringPi

	Computer B will read the encoders, calculate position data, and send the information to the desktop.
	Copy and build the program encoderMain.c onto computer B.
	# gcc encoderMain.c -o encoderMain -lwiringPi
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

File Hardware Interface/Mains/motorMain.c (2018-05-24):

#include <math.h>
#include <string.h>
#include <stdio.h>
#include <stdlib.h>
#include <wiringPi.h>
#include <wiringSerial.h>

#define debug 1
#define DEBUG(args ...) if(debug) { printf(args); }

//motor controller values
#define addr_l 128
#define addr_r 135

//pin values
#define active_l 0
#define active_r 1

#define MOTOR_MIN 0
#define MOTOR_MAX 120
#define BRAKE 16

#define PACKET_ARGS 9
#define ALL_TYPES 999

//Forward Decl
void getSerialData(int);
int processPacket(int, double, double, double, double);
void sendMotorPacket(int,int,int,int);
void clearLine(int);
void clearPacket();

void updateSpeeds();
void writeMotors();

//Serial Port Values
int serialXBee;
int serialGPIO;

//Motor Active Values
int targetL, targetR;
int speedL, speedR;
int accelDelayL, accelDelayR;
int pausingL = 0; int pausingR = 0;

//Computer Info
char delim = '|'; //delimeter for packet processing
int key = -1;
int platform = -1;
int type = 0; //type = 0 for motor brain, 1 for encoder brain.
char mac_address[256]; //MAC address of brain

//values for packet input
char key_in_str[128] = "\0";
char plat_in_str[128] = "\0";
char target_in_str[128] = "\0";
char id_in_str[128] = "\0";
char comm_in_str[128] = "\0";
char val1_in_str[128] = "\0";
char val2_in_str[128] = "\0";
char val3_in_str[128] = "\0";
char checksum_in_str[128] = "\0";

int key_in; //value should be positive int matching key
int plat_in; //value should be positive int matching platform
int target_in; //value should be positive int matching type
int id_in;
int comm_in;
double val1_in; //value should be int in range of -1024 to 1024
double val2_in; //value should be int in range of -1024 to 1024
double val3_in; //value should be int greater than 0
double checksum_in; //value should match sum of target_L_in and target_R_in

int valuesLoaded = 0;
int configured = 0;

int update = 0;

int main(int argc, char* argv)  {

	DEBUG("Starting Motor Brain...\n");

	DEBUG("MAC address: ");
	FILE *mac = fopen("/sys/class/net/eth0/address", "r");
	fgets(mac_address, 255, mac);
	fclose(mac);
	DEBUG("%s\n", mac_address);

	wiringPiSetup();
	serialXBee = serialOpen("/dev/ttyUSB0", 57600);
	serialGPIO = serialOpen("/dev/ttyS0", 9600);

	//Initialize values
	targetL = 0;
	targetR = 0;

	speedL = 0;
	speedR = 0;

	accelDelayL = 0;
	accelDelayR = 0;

	DEBUG("Activating Motors...\n");
	sendMotorPacket(addr_l, 0, 0, 0);
	sendMotorPacket(addr_r, 0, 0, 0);

	digitalWrite(active_l, HIGH);
	digitalWrite(active_r, HIGH);


	//Initialize serial

	if(serialXBee != -1 && serialGPIO != -1) {
		DEBUG("serial init successful.\n");
	}
	else {
		DEBUG("serial init failed.\n");
	}
	serialFlush(serialXBee);

	DEBUG("Waiting for Configuration...\n");

	while (configured < 2) {
		if(serialDataAvail(serialGPIO) > 0) {
			getSerialData(serialGPIO);
		}
	}

	DEBUG("Configuration Complete: key = %d, platform id = %d\n", key, platform);

	//MAIN LOOP
	while(1) {
		//Process all data in buffer
		if(serialDataAvail(serialXBee) > 0) {
			getSerialData(serialXBee);
		}
		//Set speeds closer to target speeds
		if(update > 0) {
			updateSpeeds();
			writeMotors();
		}
	}
	return 0;
}

//PROCESS SERIAL INPUT:
//Processes any waiting serial input and loads it into a packet
//Standard packet 0: sets target speeds to target_R and target_L, sets corresponding accelDelay.
//Standard packet 1: modifies attributes: 0 = key (int), 1 = platform id (int)
//E_STOP: sets target speeds, speeds, and accelDelay to 0, writes values to motors.
//PAUSE: sets target speeds to 0, accelDelays to 2 seconds (overall), calls motor update.
void getSerialData(int port) {
	int valuesLoadedLocal = 0;
	while(serialDataAvail(port) > 0 && valuesLoadedLocal < 1) {
		char c = (char)serialGetchar(port);
		DEBUG("%c", c);
		if(c == '|') {
			valuesLoaded += 1;
			valuesLoadedLocal += 1;
			//preemptively ignore packets
			switch(valuesLoaded) {
				case 1:
					key_in = atoi(key_in_str);
					if(key_in != key) {
						DEBUG("ignoring packet: key mismatch %d != %d\n", key_in, key);
						clearLine(port);
						clearPacket();
					}
					break;
				case 2:
					DEBUG("Checking for E_STOP...\n");
					if(strcmp(plat_in_str, "E_STOP") == 0) {
						DEBUG("emergency stop recieved!\n");
						//Set all values to negative of current values to kill momentum
						targetL = -targetL;
						targetR = -targetR;
						speedL = -speedL;
						speedR = -speedR;
						accelDelayL = 0;
						accelDelayR = 0;
						writeMotors();

						delay(300);

						//Set all values to stop values
						targetL = 0;
						targetR = 0;
						speedL = 0;
						speedR = 0;
						accelDelayL = 0;
						accelDelayR = 0;
						writeMotors();
						DEBUG("emergency stop processed\n");

						clearLine(port);
						clearPacket();
					}
					//DEBUG("Checking for PAUSE...\n");
					if(strcmp(plat_in_str, "PAUSE") == 0) {
						pausingL = 1;
						pausingR = 1;
						DEBUG("pause command recieved!\n");
						//Set all target values to stop
						if(targetL > 0) {
							targetL = -BRAKE;
						}
						else {
							targetL = BRAKE;
						}
						if(targetR > 0) {
							targetL = -BRAKE;
						}
						else {
							targetR = BRAKE;
						}
						accelDelayL = (int)(1000.0 / (double)speedL);
						accelDelayR = (int)(1000.0 / (double)speedR);
						update = 1;
						DEBUG("pause processed\n");

						clearLine(port);
						clearPacket();
					}

					plat_in = atoi(plat_in_str);
					if(plat_in != platform) {
						DEBUG("ignoring packet: platform mismatch\n");
						clearLine(port);
						clearPacket();
					}
					break;
				case 3:
					target_in = atoi(target_in_str);
					if(target_in != type && target_in != ALL_TYPES) {
						DEBUG("ignoring packet: type mismatch\n");
						clearLine(port);
						clearPacket();
					}
					break;
			}
		}
		//PROCESS COMPLETE PACKET:
		//Packet structure:
		//key|platform|target|id|target_L|target_R|accel_time|checkSum
		//key: key lock for establishing valid packet sending
		//platform: id of target platform: must match current platform id
		//target: target brain: 0 = motor brain, 1 = encoder brain
		//id: id of packet - used for handshake
		//target_L, target_R: target speeds for each motor
		//accel_time: time (in seconds) to accelerate to target speeds
		//checkSum: validation value == target_L + target_R + accel_time
		else if(c == '\n') {
			//Display packet info
			//DEBUG("key_in: %s\n", key_in_str);
			//DEBUG("plat_in: %s\n", plat_in_str);
			//DEBUG("target_in: %s\n", target_in_str);
			//DEBUG("id_in: %s\n", id_in_str);
			//DEBUG("comm_in: %s\n", comm_in_str);
			//DEBUG("target_L_in: %s\n", target_L_in_str);
			//DEBUG("target_R_in: %s\n", target_R_in_str);
			//DEBUG("accel_time_in: %s\n", accel_time_in_str);
			//DEBUG("checkSum_in: %s\n", checkSum_in_str);

			//process all inputs
			int ignore = 0;
			int isBad = 0;
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

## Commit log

2017-08-28 Added Encoder Driver (arduino code)
    Added encodertest.ino, which keeps track of a rotary encoder's angular
    position (0-360) relative to its initial position. Position/directional
    data is output to a series of LEDs as a part of the test.
2017-08-30 Added Ultrasonic Sensor Driver
    Added sample interface to read and interpret ultrasonic sensor values. Sample code filters erroneous values, prints 'OK' if recorded distance is within threshold, and prints 'WARNING' if the recorded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
2017-08-31 Added Circuit Diagrams, Reorganized Hardware Interface folder
    Added separate 'Circuit Diagram' and 'Sample Code' folders, added
    circuit diagrams for Encoder and Ultrasonic Sensor.
2017-08-31 Resolved Desync Issue
    Removed duplicate ultrasonictest.ino file (true file is in ./Sample
    Code)
    [ultrasonictest.ino]
2017-09-01 Added Gantt Chart
    Added .xlsx Gantt Chart for visual tracking of task
    completion/dependencies
    [Gantt Chart.xlsx]
2017-09-29 Added radio transmission/serial read dummy files
    Added radio test and dummy serialread file. Added Gannt Chart and Bumper
    circuit diagram.
    [Gantt Chart.xlsx]
2017-09-30 Added Encoder Mount Drawing
    Added AutoCAD drawing of mount for encoders used in The Nether.
    [EncoderMount.dwg]
2017-10-06 Added Test Serial Read Code
    Added code using node serialport library that should read each non-null
    character from the assigned serial port and print it to the console.
    Currently, it is not functional.
2017-10-07 Added UDP Packet Send
    Added functionality to Serial Interface code that sends a UDP packet to
    a specific port based on which radio sent the message to serial.
    Currently sends to localhost, should be editable without much trouble.
2018-01-08 Added Serial Reciever, Design Notes
    Added JS serial reader for communication with XBee (note: program does
    not send signals, only recieves). Added design notes for Raspberry PI
    configuration, RPI encoder interface, and RPI motor interface. Added
    platform pricing/sourcing information.
    [Configuration.txt, Platform Pricing.xlsx]
2018-01-08 Updated Wiring, Pricing Details
    Added pin numbers for RPI wiring, added materials costs for platform
    pricing. Price remains below $2000.
    [Platform Pricing.xlsx]
2018-01-21 Updated Raspberry Pi Config Notes, added RPi Test Code
    Updated RPi config to a method that requires no internet connection.
    Brought test code from RPi into current repo. Current test code
    processes encoder, motor, and serial to/from XBee. Reorganized Hardware
    Interface directory.
    [Configuration.txt]
2018-01-26 Updated Circuit Diagrams/Motor Notes
    Added (hopefully) final circuit diagram - parallel batteries, two
    computers, etc etc
2018-02-12 Updated Main Circuit Diagram, Added Main Loops
    Updated Circuit Diagram to account for new power layout. Added the
    following files:
    - encoderMain.c: The first version of the main loop for the encoder
    brain. Reads encoder changes, calculates x,y, and theta, and broadcasts
    position packet.
    - motorMain.c: The first version of the main loop for the motor brain.
    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
2018-03-02 Updated Config Document
    Updated configuration document to include enabling UART serial port.
    Minor changes to other steps.
    [Configuration.txt]
2018-03-13 Updated Main Programs
    motorMain.c now processes generic packets and E_STOP packets. Additions:
    accel_time, motor updates, finalized interface for motor controllers
    using UART serial.
    encoderMain.c now has more efficient packet processing, using dynamic
    update sizing to prevent issues with interrupt overloads when updates
    need to be send to the central control.
    [encoderMain.c, motorMain.c]
2018-03-13 Modified/Tested New Mains
    motorMain.c:
    - Confirmed functionality of emergency stop processing.
    encoderMain.c:
    - Added packet processing for setPos and modifyAttribute commands.
    setPos sets x, y, and theta. modifyAttribute modifies key, platform id,
    base width, or radius of encoder wheels.
    - Improved update limiter rules by binding match_limit to update_size.
    [encoderMain.c, motorMain.c]
2018-03-20 User Interface Inital Commit 🎉 It's here, it's here, it's finally here! Introducing the UI!
2018-03-20 Improved Packet Processing, added MAC address fetch
    Added attribute TICKS_PER_CYCLE for attributes modification. Added functionality for general platform broadcast (recieved by both motor and encoder brains) - used to set key/platform id.
    Revised packet processing to account for PAUSE commands and attribute modification. Permissible attributes to modify are key and platform id. Cleaned up command processing.
    Both:
    Added MAC address fetch from /sys/class/net/eth0/address.
    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
2018-03-21 Added Incomplete Path-Finding Sim
    Added matlab simulation to demonstrate path-following algorithm.
    ac_path_following takes in a vector of position vectors (x,y,theta), an
    initial position vector, and the number of cycles to take.
    Currently, the simulation only calculates the intersection between the
    normals of the platform and the next waypoint.
    TODO:
    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
2018-03-26 Added path following logic to simulation
    Added test cases and path following logic to simulation.
    Added coverage of edge cases to waypoint passage check.
    Currently, the simulation only handles counter-clockwise motion. The
    next step is to dynamically determine which direction to turn, rather
    than only determining how hard the platform should turn.
2018-03-26 Added robustness to path following, basic encoderMain fixes
    encoderMain.c
    Accounted for directional difference in encoder rotations.
    ac_path_following.m
    Added handling for cw/ccw path following, parallel trajectories, etc.
    [encoderMain.c]
2018-04-03 Updated Mains, Path Following
    encoderMain.c and motorMain.c:
    - Updated variable names to be consistent across programs
    motorMain.c
    - Added pause/emergency stop functionality
    - Removed defunct variables
    - Improved packet handling
    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
2018-04-05 Final Pre-Defense Update
    - Corrected dtheta calculation
    - Added PING response
    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
    [encoderMain.c]
2018-04-08 Removed User Interface folder Seperating controller into another repo
    [EncoderMount.dwg]
2018-05-24 Added Configuration, Revised Packet Processing, Revised Raspberry Pi Configuration
    encoderMain.c, motorMain.c:
    - Added configuation protocol. On startup, platform will broadcast its MAC address until it receives a response from the controller. This will ensure that the platform has the correct settings before it begins encoder tracking and motor listening.
    - Added an affordance to both getSerialData() methods, ensuring that only one value is loaded per method call. This will ensure that if the platform is flooded with packets, the motors will continue to operate.
    Configuration.txt:
    - Fixed path for enabling UART interface.
    [Configuration.txt]
